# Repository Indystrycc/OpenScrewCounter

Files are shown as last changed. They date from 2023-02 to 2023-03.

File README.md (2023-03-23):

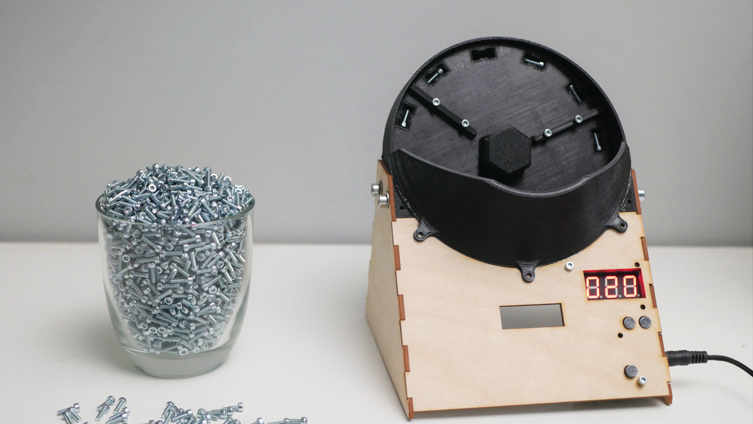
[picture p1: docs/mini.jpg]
OpenScrewCounter


Designed by [Nikodem Bartnik](https://www.youtube.com/nikodembartnik). 

OpenScrewCounter is a machine built to count various small screws. It was built to simplify the counting procedure of set of screws for [IndyMill CNC machine](http://indystry.cc/indymill/). Researching similar solutions resulted in rejecting a few early ideas for the design of this project and in the end a approach presented above was implemented. At this stage the machine is not perfect and some upgrades are required to make it production ready. 

## Open Source
Project is open source and all the files and the code are available above. Feel free to use it, modify and share with others. Contributing to the project is more than welcome! 

## Parts
 - [Raspberry Pi Pico](https://amzn.to/3FnSxVT)
 - [Motor](https://amzn.to/405kJVr)
 - [7 segment display](https://bit.ly/40bwYQB)
 - [Buttons](https://amzn.to/3yK9nul)
 - [6804 Bearing](https://amzn.to/40ppZDR)
 - [Some screws](https://amzn.to/3leCWBm)

## Videos

(https://youtu.be/acUexuxC3fU)

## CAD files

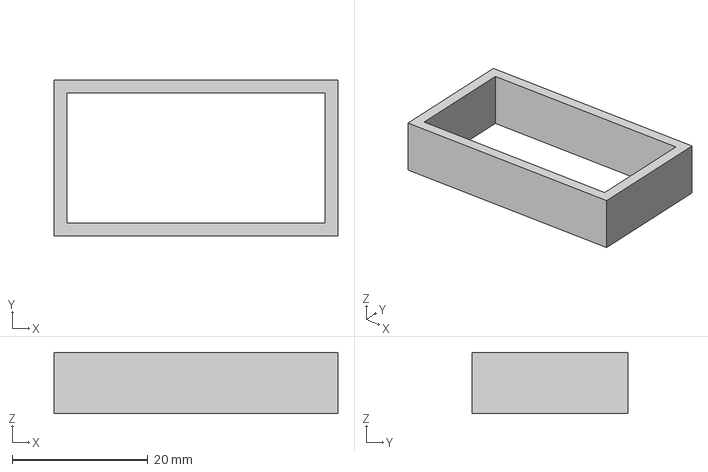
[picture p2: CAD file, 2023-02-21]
3D printed/screen tunnel.3mf
41.8 x 23.0 x 9.00 mm

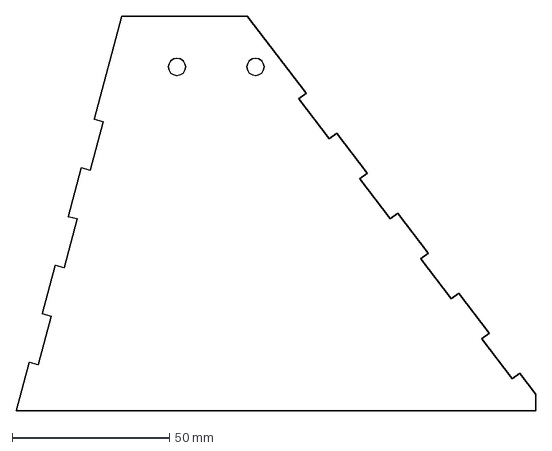
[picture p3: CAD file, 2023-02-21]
laser cut/side panel.dxf
165.4 x 125.6 mm

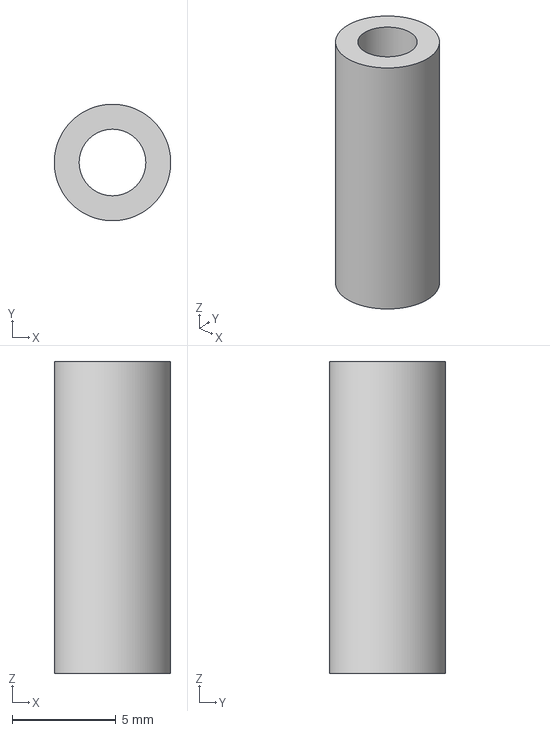
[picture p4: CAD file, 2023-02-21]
3D printed/pcb distance.3mf
5.60 x 5.60 x 15.0 mm

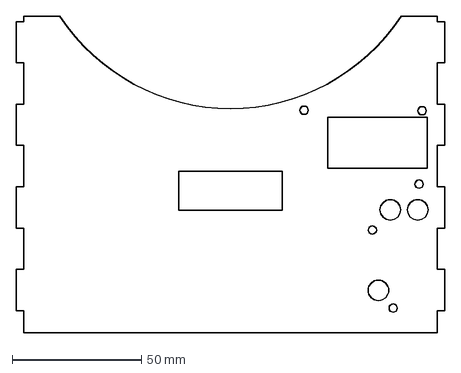
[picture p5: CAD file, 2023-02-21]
laser cut/front panel.dxf
166.0 x 122.5 mm

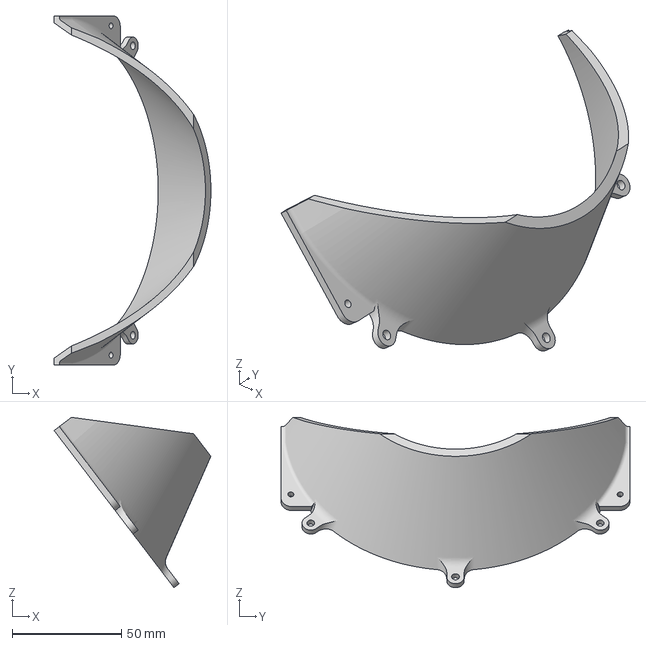
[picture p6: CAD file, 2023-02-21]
3D printed/drum extender.3mf
71.9 x 160.0 x 78.1 mm

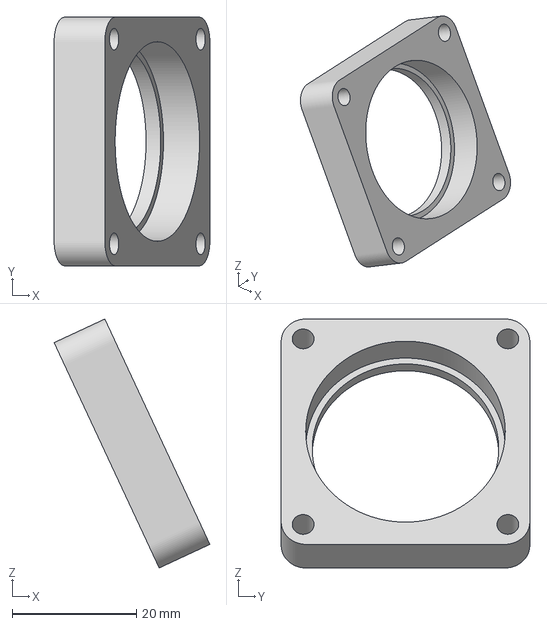
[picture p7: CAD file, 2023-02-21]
3D printed/6804 holder.3mf
25.1 x 40.0 x 40.1 mm

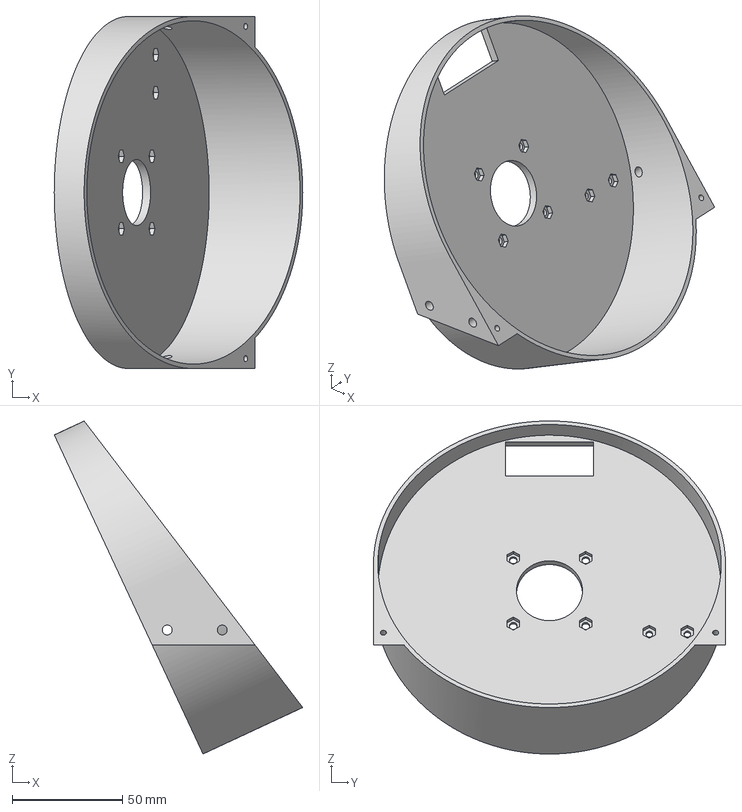
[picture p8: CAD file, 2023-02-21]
3D printed/drum.3mf
112.9 x 160.0 x 151.3 mm

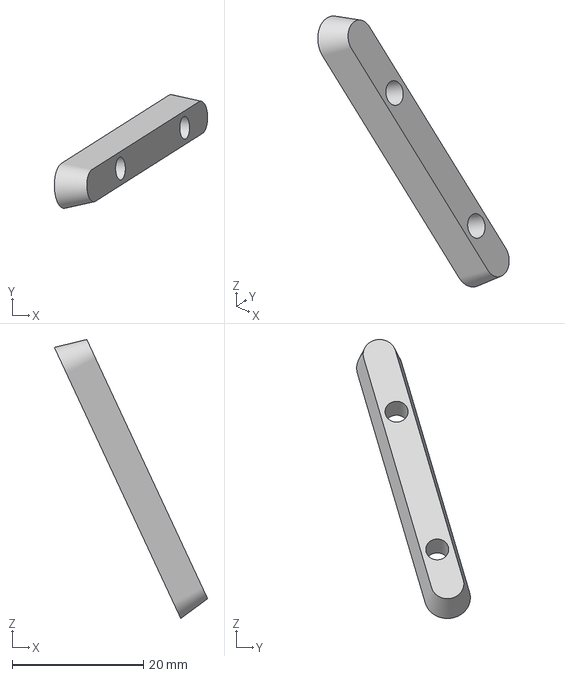
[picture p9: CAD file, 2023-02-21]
3D printed/mixer.3mf
23.4 x 17.3 x 42.6 mm

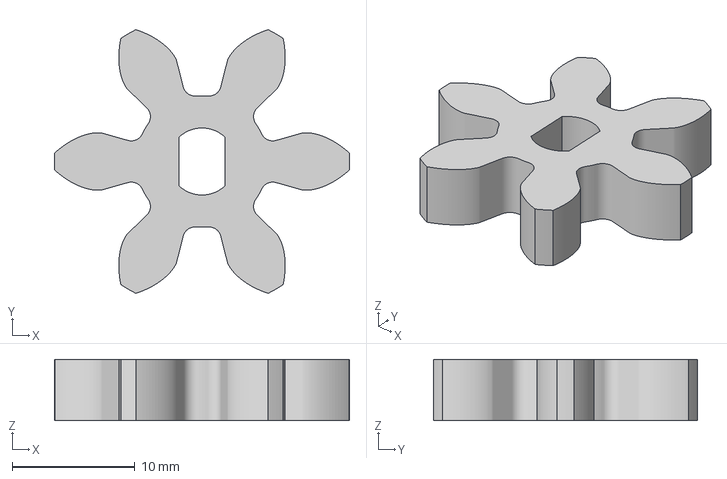
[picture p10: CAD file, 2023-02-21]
3D printed/motor gear.3mf
24.0 x 21.5 x 5.00 mm

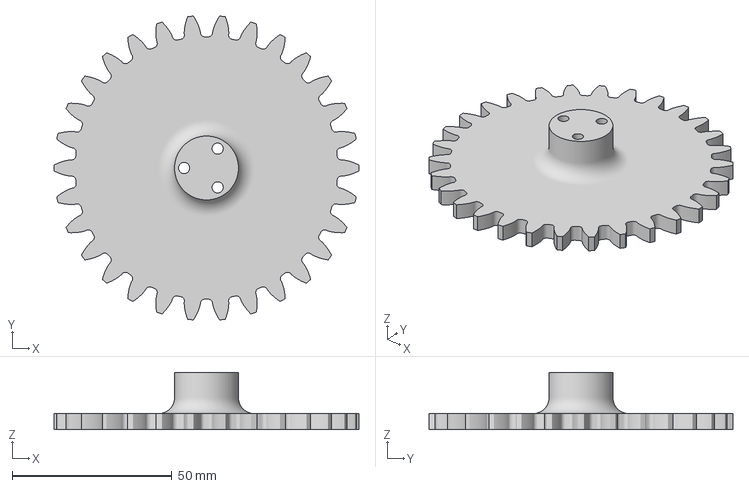
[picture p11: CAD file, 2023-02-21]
3D printed/shaft gear.3mf
95.4 x 95.1 x 17.9 mm

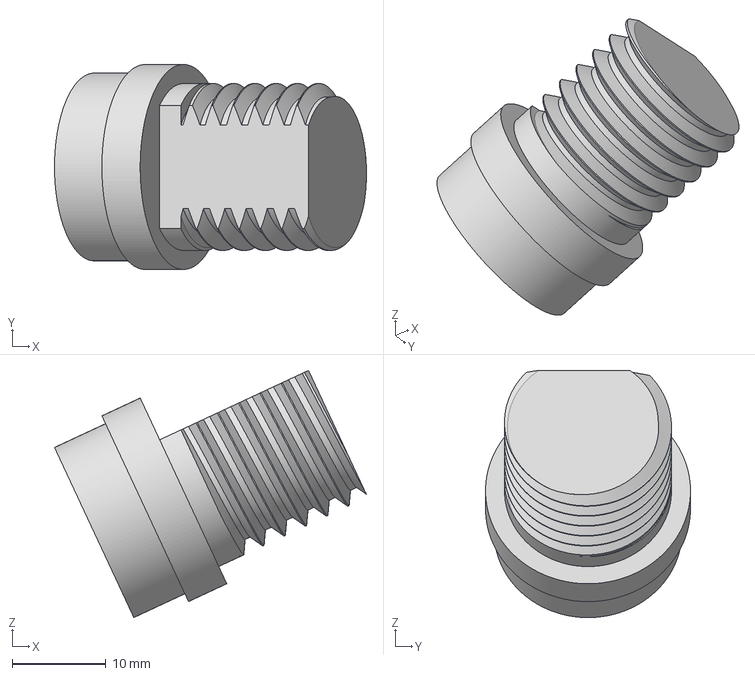
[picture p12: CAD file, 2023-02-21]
3D printed/shaft.3mf
33.2 x 21.8 x 26.3 mm

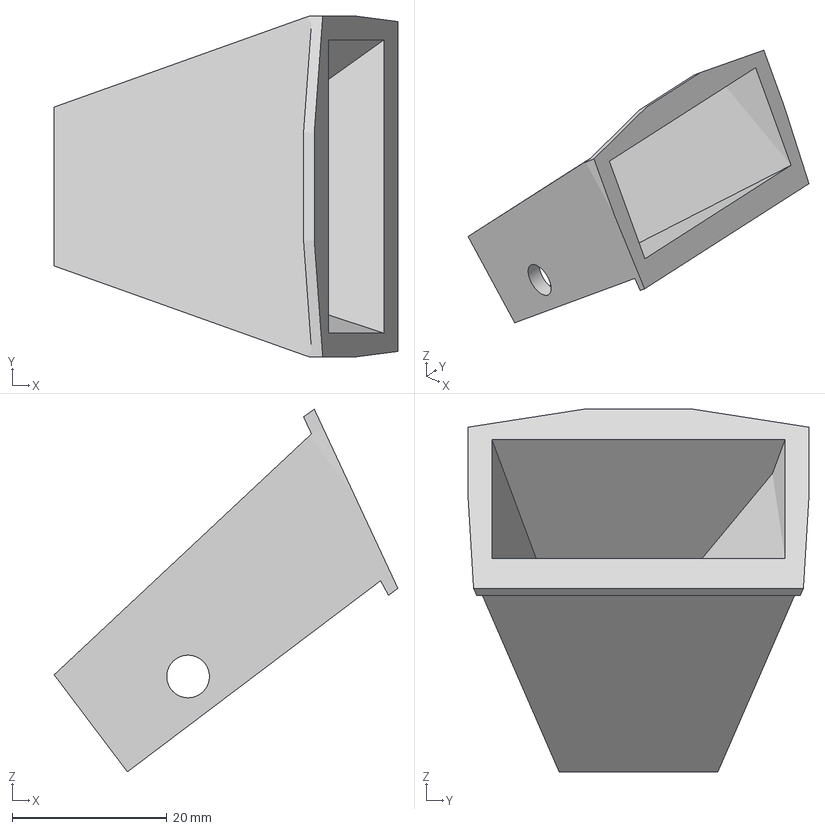
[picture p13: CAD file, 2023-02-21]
3D printed/funnel.3mf
44.4 x 44.0 x 46.8 mm

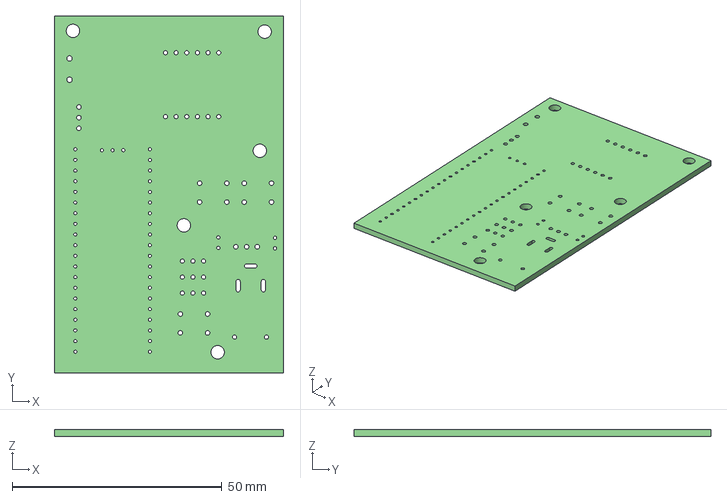
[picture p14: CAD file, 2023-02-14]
pcb/OpenScrewCounter.step
54.6 x 85.1 x 1.60 mm

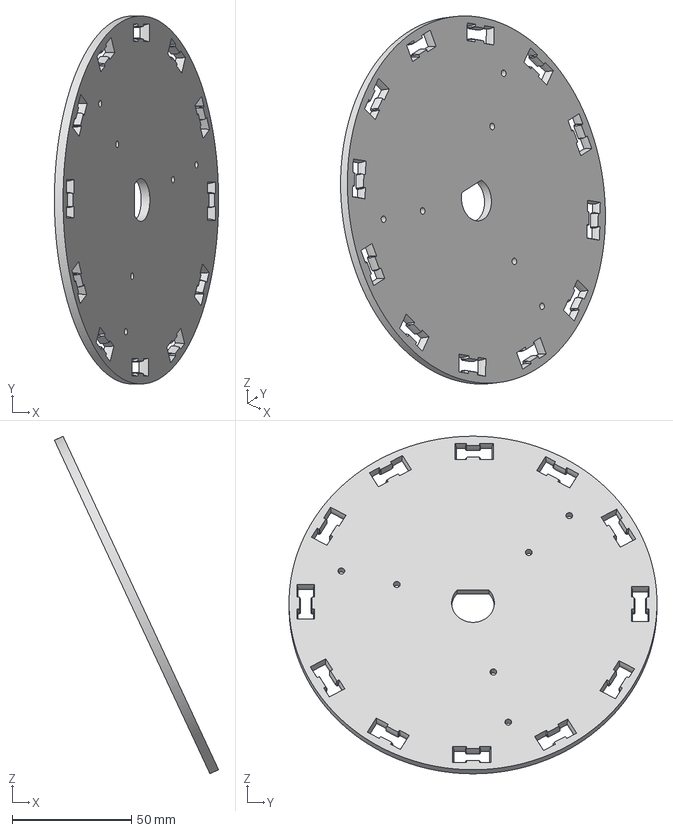
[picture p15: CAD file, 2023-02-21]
3D printed/M3x10 screw wheel.3mf
68.7 x 154.0 x 141.2 mm

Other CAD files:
3D printed/wheel nut.3mf
pcb/OpenScrewCounter.3mf

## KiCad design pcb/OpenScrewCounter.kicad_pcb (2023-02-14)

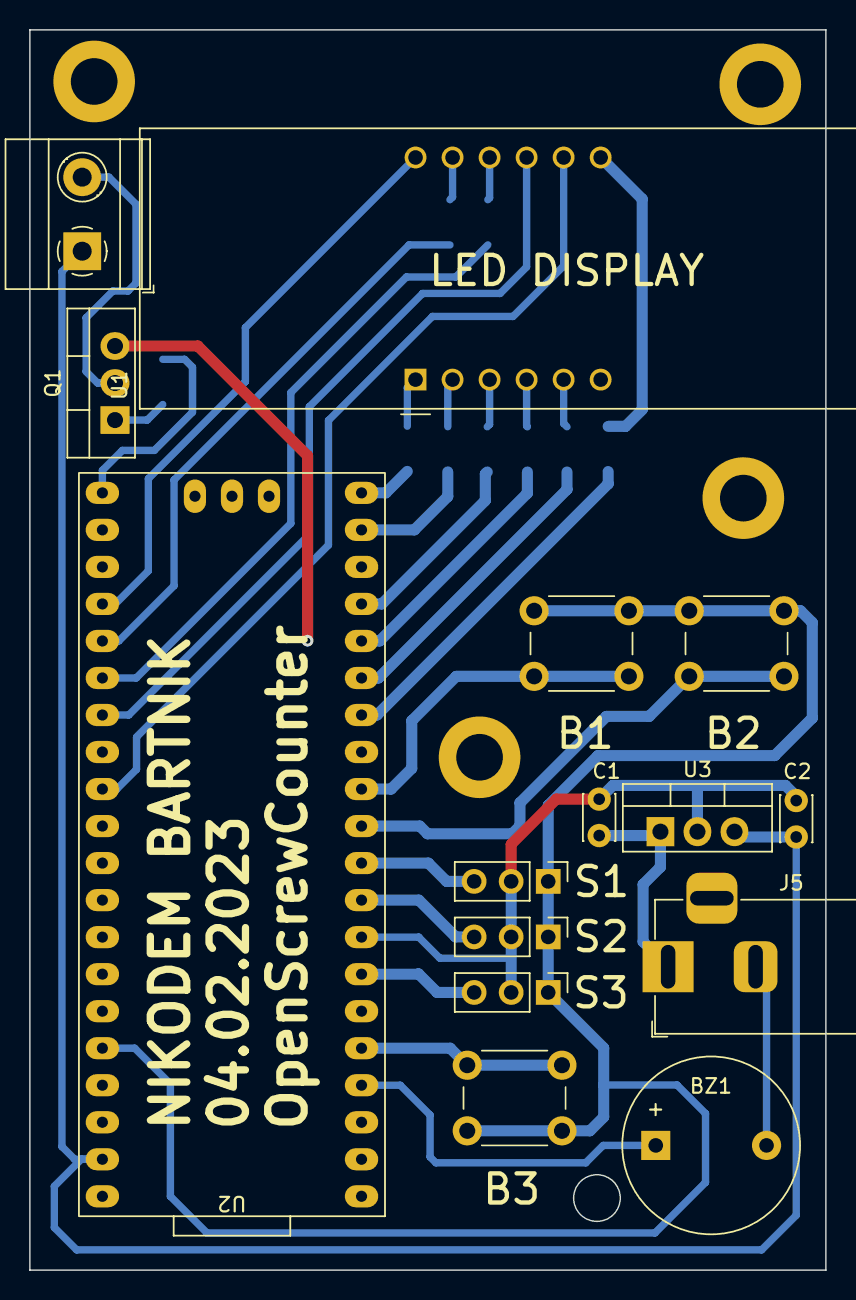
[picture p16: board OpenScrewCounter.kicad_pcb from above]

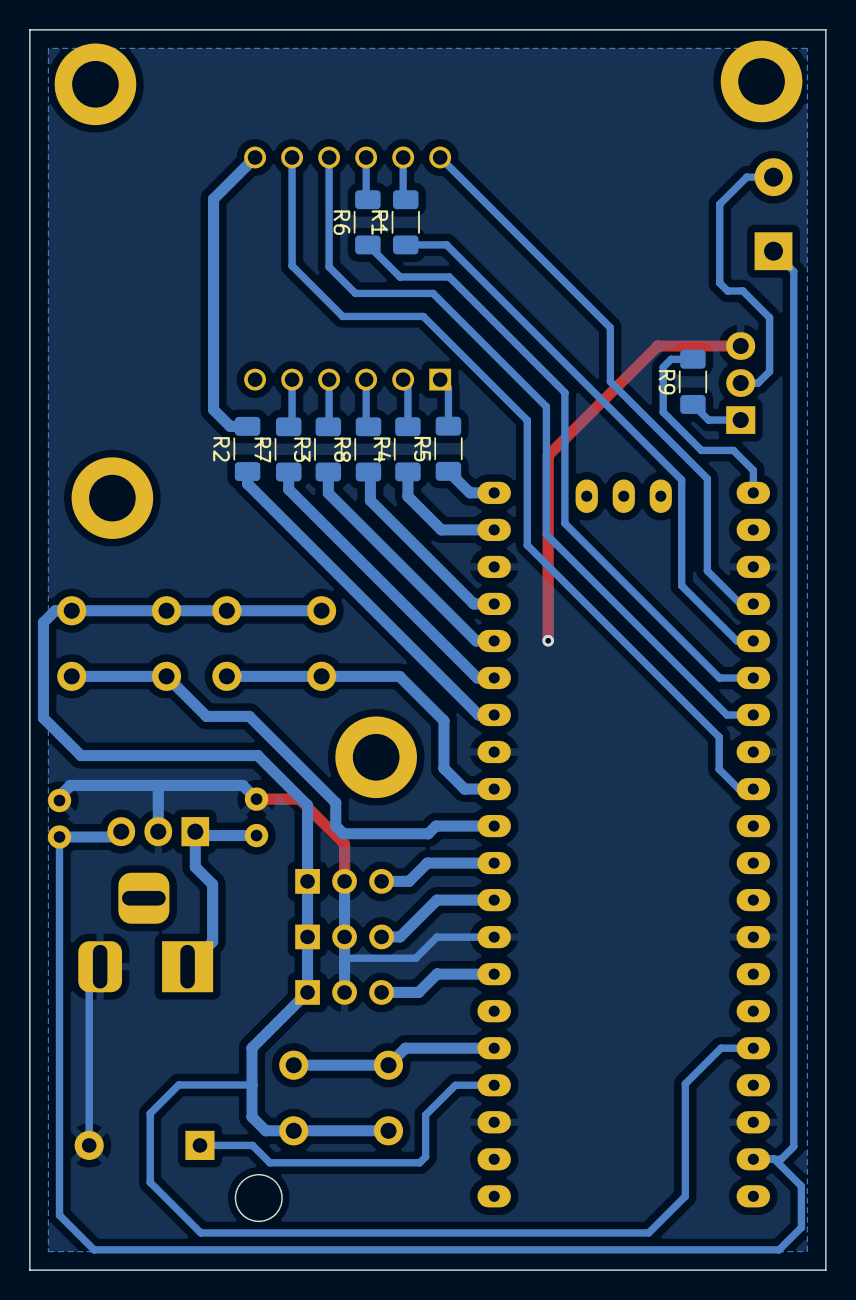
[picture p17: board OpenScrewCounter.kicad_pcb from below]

Board: 2 copper layers, 54.6 x 85.1 mm, 24 parts (9 on the bottom side), 33 nets.

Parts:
BZ1: Buzzer; Buzzer_12x9.5RM7.6
C1: 100u; C_Disc_D3.0mm_W2.0mm_P2.50mm
C2: 10u; C_Disc_D3.0mm_W2.0mm_P2.50mm
J2: P1; TerminalBlock_Phoenix_MKDS-1,5-2-5.08_1x02_P5.08mm_Horizont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
J5: Barrel_Jack_MountingPin; BarrelJack_Horizontal
Q1: IRFZ44N; TO-220-3_Vertical
R1, R2, R3, R4, R5, R6, R7, R8: 330; R_1206_3216Metric_Pad1.30x1.75mm_HandSolder
R9: 10k; R_1206_3216Metric_Pad1.30x1.75mm_HandSolder
S1, S2, S3: Sensor; PinHeader_1x03_P2.54mm_Vertical
SW1, SW2, SW3: SW_Push; SW_PUSH_6mm_H7.3mm
U1: CA56-12EWA
U2: pi pico; raspberry pi pico
U3: L7805; TO-220-3_Vertical

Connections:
+3V3: S1.1, S2.1, S3.1, SW1.1, SW2.1, SW3.1, U2.36 (3V3(OUT))
+5V: C2.1, J2.1, U2.39 (VSYS), U3.3 (OUT)
+12V: C1.1, J5.1, U3.1 (IN)
BUTTON1: SW3.2, U2.5 (GP3)
BUTTON2: SW2.2, U2.11 (GP8)
BUTTON3: SW1.2, U2.12 (GP9)
BUZZER: BZ1.1 (-), U2.4 (GP2)
DIG1: U1.12 (CA1), U2.24 (GP18)
DIG2: U1.9 (CA2), U2.27 (GP21)
DIG3: U1.8 (CA3), U2.29 (GP22)
DIS_A: R1.1, U2.25 (GP19)
DIS_B: R2.1, U2.14 (GP10)
DIS_C: R3.1, U2.16 (GP12)
DIS_D: R4.1, U2.19 (GP14)
DIS_DP: R8.1, U2.17 (GP13)
DIS_E: R5.1, U2.20 (GP15)
DIS_F: R6.1, U2.26 (GP20)
DIS_G: R7.1, U2.15 (GP11)
GND: BZ1.2 (+), C1.2, C2.2, J5.2, Q1.3 (S), S1.2, S2.2, S3.2, U2.3 (GND), U2.8 (GND), U2.13 (GND), U2.18 (GND), U2.23 (GND), U2.28 (GND), U2.33 (GND), U2.38 (GND), U3.2 (GND)
MOTOR: R9.2, U2.21 (GP16)
unnamed: J2.2, Q1.2 (D)
unnamed: Q1.1 (G), R9.1
unnamed: R1.2, U1.11 (a)
unnamed: R2.2, U1.7 (b)
unnamed: R3.2, U1.4 (c)
unnamed: R4.2, U1.2 (d)
unnamed: R5.2, U1.1 (e)
unnamed: R6.2, U1.10 (f)
unnamed: R7.2, U1.5 (g)
unnamed: R8.2, U1.3 (DPX)
SENSOR1: S1.3, U2.10 (GP7)
SENSOR2: S2.3, U2.9 (GP6)
SENSOR3: S3.3, U2.7 (GP5)

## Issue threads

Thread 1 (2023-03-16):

Ideas for improvement

chazp246, 2023-03-16:
Hi,
Really interesting video and I have some ideas that could make it better.
I think you have a problem with the detection sometimes registering the srew multiple times right? You could place a delay after each srew. That way it would eliminate this error.
Better idea would be to use the same system but place it elsewhere. You could have the sensor looking at the wheel one position before the drop there would be light barrier going through that path. If there is nothing in the slot there will be gap that is certain time. If there is the screw the gap is not present and you could make a lot more accurate.

The best course of action (from my perspective) is to have circle and on that circle all the different slots will have their mid point. Somewhere close to drop off there would be optical barrier going though the part plate with sensor right above the circle. With this you only change the part wheel for different kind of screw and also change parameter in the setup. You could also get rid off that optical barrier and use induction sensor something like pinda probe on prusa. It Could work with the screws and the plastic wont set it off, but I am not too sure if the small screw will set it off.

SOO inductive probe/optical

Sorry I am not the best when it comes to expressing ideas in written form.

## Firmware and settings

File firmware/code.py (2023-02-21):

from machine import Pin, ADC, Timer, PWM
from time import sleep
import time

motor = PWM(Pin(16))
motor.freq(1000)

buzzer = Pin(2, Pin.OUT)

DIS_A = Pin(19, Pin.OUT)
DIS_B = Pin(10, Pin.OUT)
DIS_C = Pin(12, Pin.OUT)
DIS_D = Pin(14, Pin.OUT)
DIS_E = Pin(15, Pin.OUT)
DIS_F = Pin(20, Pin.OUT)
DIS_G = Pin(11, Pin.OUT)
DIS_DP = Pin(13, Pin.OUT)

DIS_DIG_1 = Pin(18, Pin.OUT)
DIS_DIG_2 = Pin(21, Pin.OUT)
DIS_DIG_3 = Pin(22, Pin.OUT)

dis_value = 0

all_segments = [DIS_A, DIS_B, DIS_C, DIS_D, DIS_E, DIS_F, DIS_G, DIS_DP]
segments = {
    0: [DIS_A, DIS_B, DIS_C, DIS_D, DIS_E, DIS_F],
    1: [DIS_B, DIS_C],
    2: [DIS_A, DIS_B, DIS_G, DIS_E, DIS_D],
    3: [DIS_A, DIS_B, DIS_C, DIS_D, DIS_G],
    4: [DIS_F, DIS_G, DIS_B, DIS_C],
    5: [DIS_A, DIS_F, DIS_G, DIS_C, DIS_D],
    6: [DIS_A, DIS_F, DIS_E, DIS_D, DIS_C, DIS_G],
    7: [DIS_A, DIS_B, DIS_C],
    8: [DIS_A, DIS_B, DIS_C, DIS_D, DIS_E, DIS_F, DIS_G],
    9: [DIS_A, DIS_B, DIS_C, DIS_D, DIS_F, DIS_G]
}

def pad_with_zeros(number, length=3):
    number_str = str(number)
    while len(number_str) < length:
        number_str = '0' + number_str
    return number_str

def display_number(number):
    # Convert the number to a string and pad it with leading zeros if necessary
    number_str = pad_with_zeros(number)
    # Loop through each digit
    for i in range(3):
        # Activate the appropriate digit pin
        if i == 0:
            DIS_DIG_1.value(1)
            DIS_DIG_2.value(0)
            DIS_DIG_3.value(0)
        elif i == 1:
            DIS_DIG_1.value(0)
            DIS_DIG_2.value(1)
            DIS_DIG_3.value(0)
        else:
            DIS_DIG_1.value(0)
            DIS_DIG_2.value(0)
            DIS_DIG_3.value(1)
        # Get the segments for the current digit
        segments_for_digit = segments[int(number_str[i])]
        # Turn on the segments for the current digit
        for segment in segments_for_digit:
            segment.value(0)
        # Wait for a short time to allow the human eye to see the digits
        sleep(0.002)
        # Turn off the segments for the current digit
        for segment in all_segments:
            segment.value(1)
            
def timer_callback(timer):
    display_number(dis_value)


led = Pin(25, Pin.OUT)
sen = machine.ADC(26)
print('ready')
timer= Timer(mode=Timer.PERIODIC, period=5, callback=timer_callback)


def motorOn():
    motor.duty_u16(50000)


def motorOff():
    motor.duty_u16(0)


def countOneScrew():
    motorOn()
    while(sen.read_u16() < 13000):
        pass
    motorOff()
    sleep(0.02)
    return True

        
def countScrews(amount):
    global dis_value
    counter = 0
    for x in range(amount):
        countOneScrew()
        counter += 1
        dis_value = counter
        
def beep():
    for x in range(2):
        buzzer.on()
        sleep(0.1)
        buzzer.off()
        sleep(0.05)

while(1):
    dis_value = 0
    countScrews(10)
    sleep(0.3)
    beep()
    sleep(3)

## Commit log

2023-02-03 added initial PCB files
    [OpenScrewCounter.kicad_pcb, OpenScrewCounter.kicad_sch]
2023-02-04 testing script LCD and buzzer
    [code.py]
2023-02-04 new version of slide2
    [slide2.3mf]
2023-02-04 drum update
    [drum.3mf]
2023-02-04 pcb update
    [OpenScrewCounter.kicad_pcb, OpenScrewCounter.kicad_sch]
2023-02-14 pcb gcode and fix
    [OpenScrewCounter.3mf, OpenScrewCounter.kicad_pcb, OpenScrewCounter.step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]
2023-02-14 printed files update
    [drill_tool_TEMP.3mf, drum extender.3mf, mixer.3mf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]
2023-02-21 update printed parts
    [6804 holder.3mf, drum.3mf, funnel.3mf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]
2023-02-21 add plates dxf files
    [front panel.dxf, side panel.dxf]
2023-02-21 update printed files
    [608 bearing holder.3mf, 6804 holder.3mf, M3x10 screw wheel.3mf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]
2023-02-21 added files for PCB
    [pcb distance.3mf, screen tunnel.3mf]
2023-03-23 PCB clean up
    [OpenScrewCounter.3mf, OpenScrewCounter.kicad_pcb, OpenScrewCounter.kicad_sch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]
